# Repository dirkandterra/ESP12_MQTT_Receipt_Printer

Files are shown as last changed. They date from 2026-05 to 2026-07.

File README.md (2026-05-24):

# ESP-12 MQTT Receipt Printer

Controls a generic 58mm ESC/POS thermal printer over UART from an ESP-12 (ESP8266) module. Subscribes to an MQTT topic and prints any message received.

## Hardware

| Signal | ESP-12 pin | Notes |
|---|---|---|
| UART TX | GPIO2 (UART1) | Connect to printer RX |
| GND | GND | Common ground with printer |

UART1 on ESP8266 is TX-only (GPIO2), which is sufficient — ESC/POS printers do not require RX for normal printing.

Printer power: most 58mm printers need 5–9 V at up to 2 A. Do **not** power from the ESP module.

## Configuration

Copy `main/secret.h.example` to `main/secret.h` and fill in your credentials:

```c
#define WIFI_SSID      "your_ssid"
#define WIFI_PWD       "your_password"
#define MQTT_SERVER    "your.broker.ip"
#define MOSQUITTO_USR  "username"
#define MOSQUITTO_PWD  "password"
```

The MQTT topic is defined in `main/main.c`:
```c
const char *mqtt_topic = "ESP12_Receipt/print";
```

Printer settings (UART port, baud rate) are in `idf.py menuconfig` → Receipt Printer.

## Build

Requires [ESP8266_RTOS_SDK](https://github.com/espressif/ESP8266_RTOS_SDK) v3.4 or later.

```bash
export IDF_PATH=/path/to/ESP8266_RTOS_SDK
idf.py build
idf.py -p /dev/ttyUSB0 flash
```

## Behaviour

- On boot, the IP address is printed on the receipt paper.
- Any message published to the MQTT topic is printed in Font B (condensed).
- WiFi: retries 5 times on disconnect, then pauses 5 minutes before trying again.
- MQTT: auto-reconnects indefinitely; re-subscribes on each reconnect.

## Project structure

```
main/
  main.c            WiFi init, MQTT topic, app entry
  printer.c/.h      ESC/POS UART driver
  mqtt_printer.c/.h MQTT subscriber → printer
  secret.h          WiFi & MQTT credentials (not in repo)
```

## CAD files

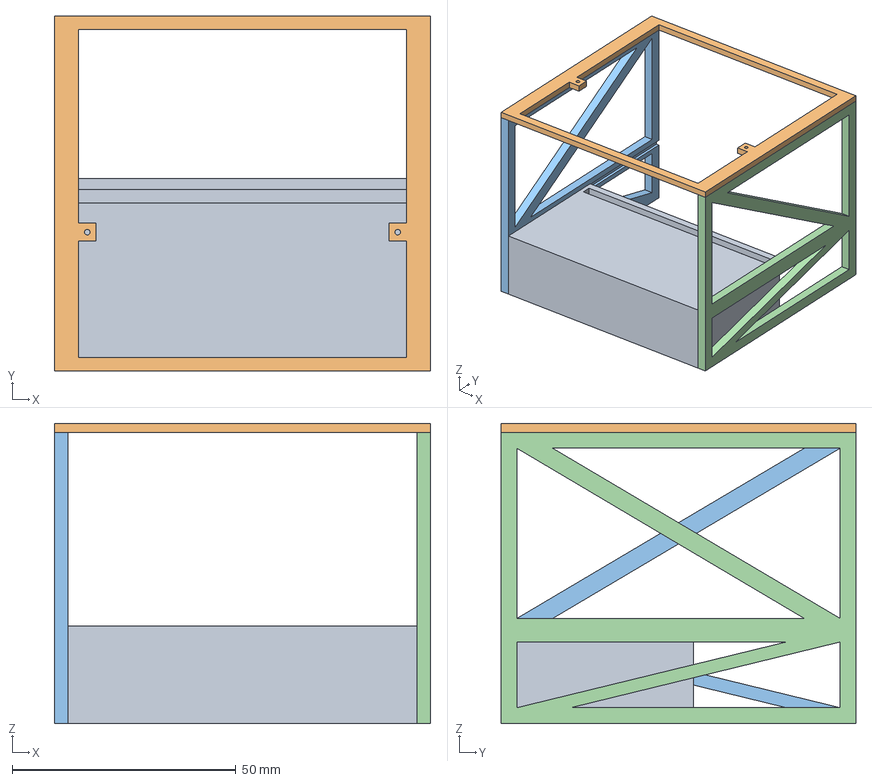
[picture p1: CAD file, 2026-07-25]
CAD/ReceiptPrinterAssembly.FCStd
84.0 x 79.3 x 67.0 mm

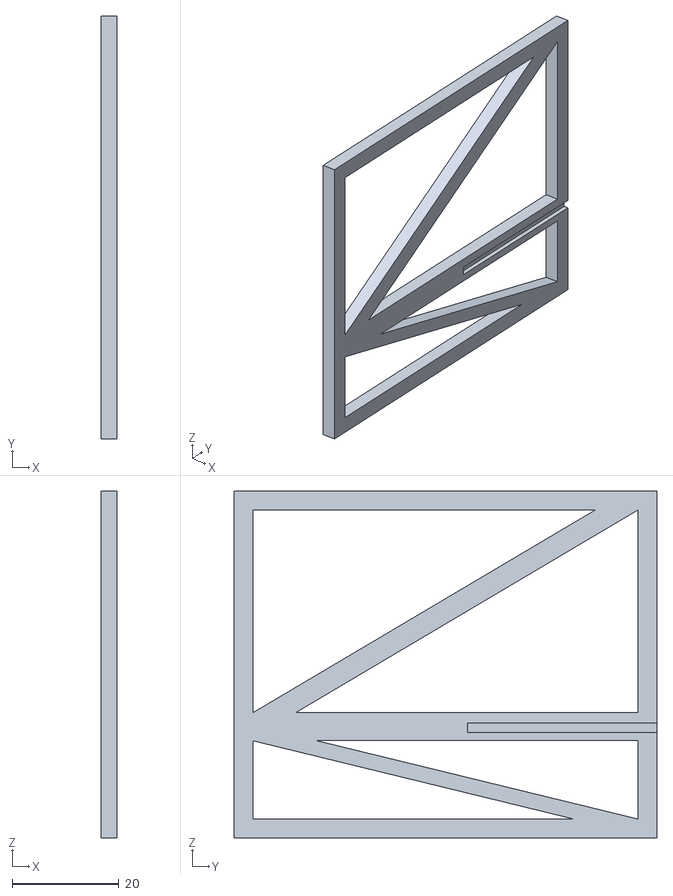
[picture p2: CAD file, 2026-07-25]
CAD/ReceiptPrinterSide1.stl
3.00 x 79.2 x 65.0

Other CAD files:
CAD/ReceiptPrinterSide2.stl

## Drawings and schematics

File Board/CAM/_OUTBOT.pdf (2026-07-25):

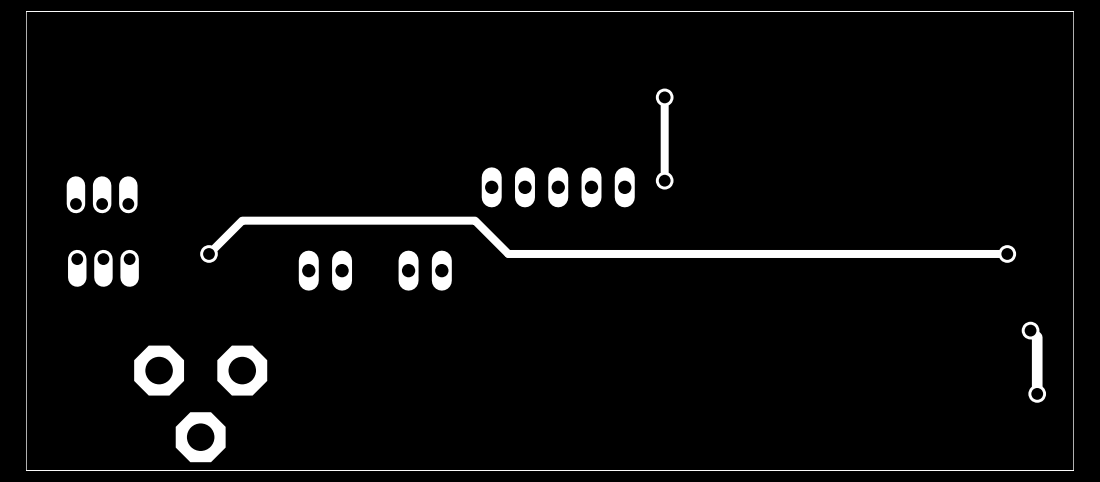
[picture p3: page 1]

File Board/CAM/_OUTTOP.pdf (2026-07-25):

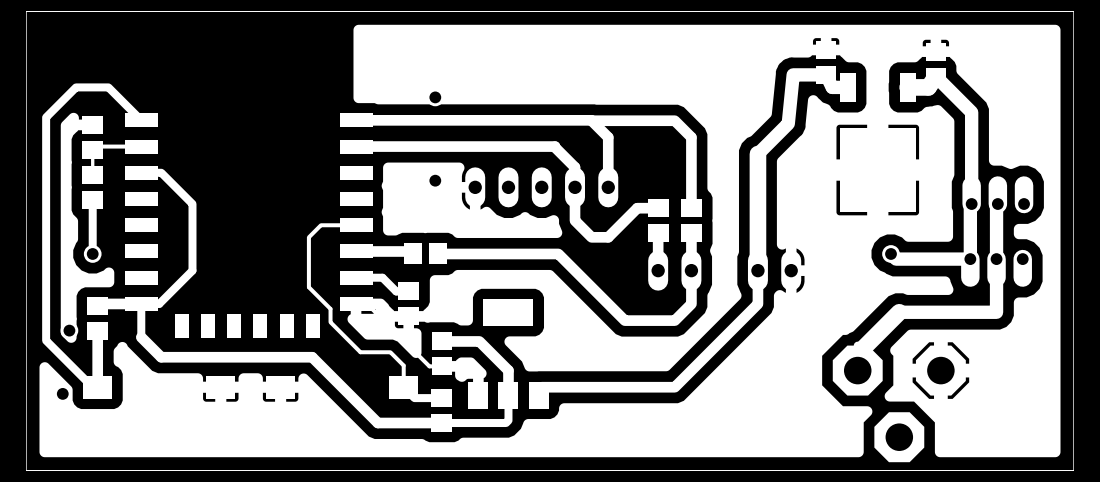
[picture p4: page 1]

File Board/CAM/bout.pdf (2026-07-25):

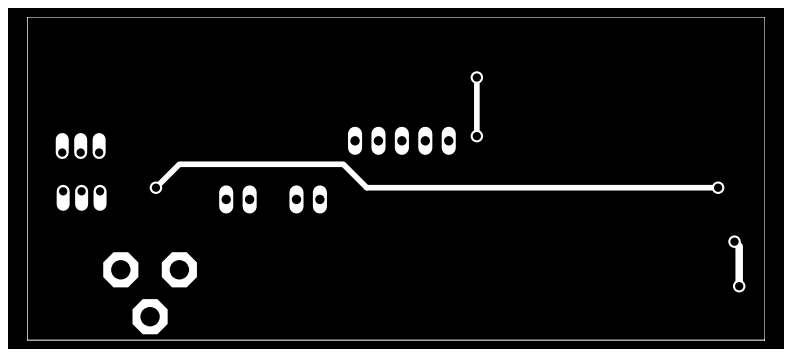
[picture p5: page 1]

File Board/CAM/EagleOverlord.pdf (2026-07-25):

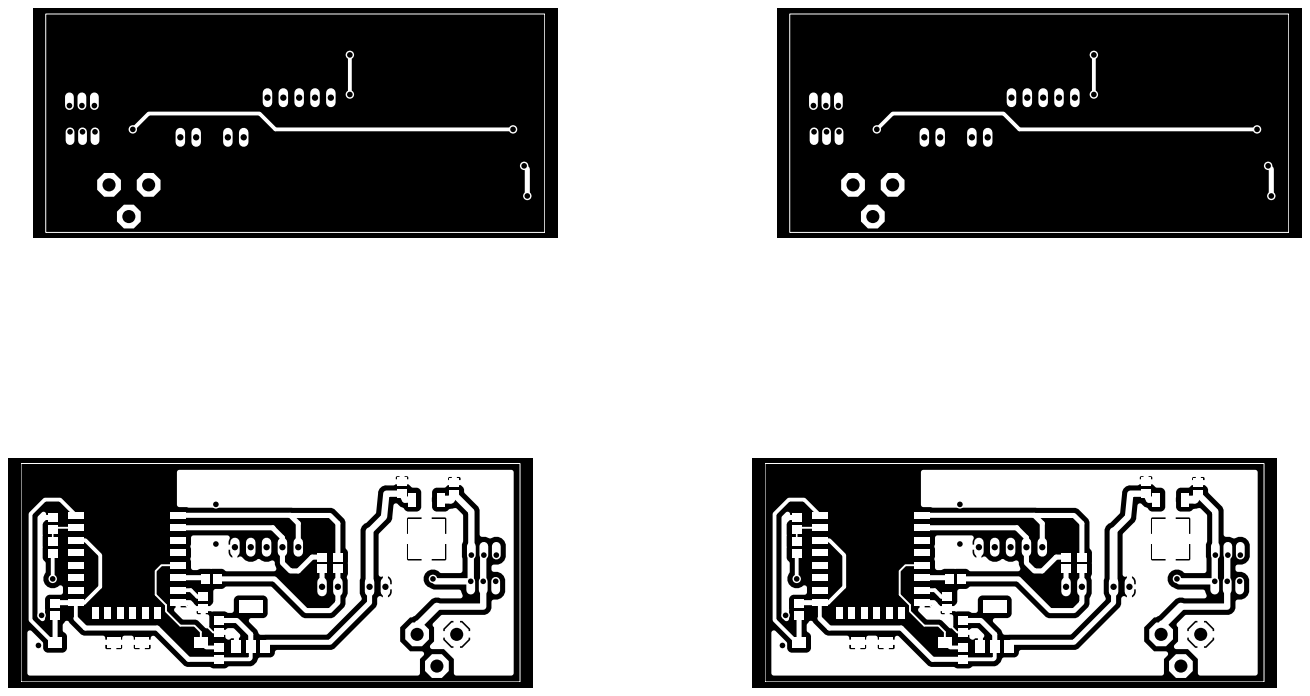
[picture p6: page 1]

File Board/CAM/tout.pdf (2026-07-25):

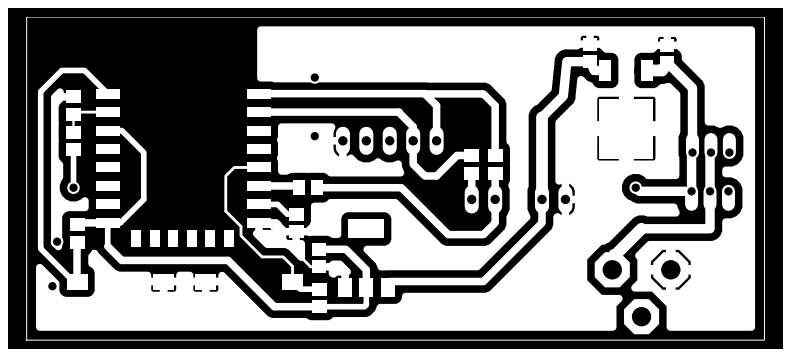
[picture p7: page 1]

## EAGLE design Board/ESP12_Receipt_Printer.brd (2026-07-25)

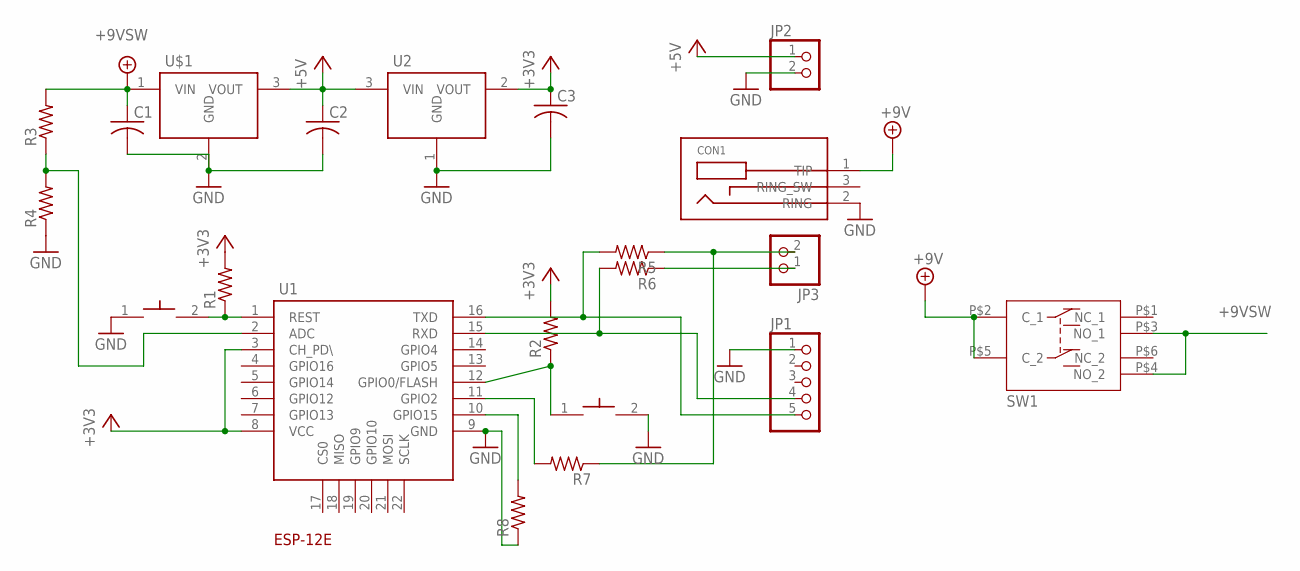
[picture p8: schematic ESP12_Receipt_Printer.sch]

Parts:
BTN1, BTN2: FSMSM_SWITCH_6X3.6; SMD-2-SWITCH
C1, C2, C3: C-USC0805; C0805
CON1: BARREL_JACK_3PINPJ-102A_2MM_HOLES; PJ-102A_2MM_HOLES
JP1: PINHD-1X5/90; 1X05/90
JP2, JP3: PINHD-1X2/90; 1X02/90
R1, R2, R3, R4, R5, R6, R7, R8: R-US_M0805; M0805
SW1: SW_TOGGLE_6PIN_DPDT; BTN_6PIN
U1: ESP-12E
U2: AMS1117; SOT223
U$1: 7805; TO252-3

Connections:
+3V3: C3.1, R1.2, R2.2, U1.3 (CH_PD\), U1.8 (VCC), U2.2 (VOUT)
+5V: C2.1, JP2.1, U2.3 (VIN), U$1.3 (VOUT)
+9VSW: C1.1, R3.2, SW1.P$3 (NO_1), SW1.P$4 (NO_2), U$1.1 (VIN)
+9V_SW: CON1.1 (TIP), SW1.P$2 (C_1), SW1.P$5 (C_2)
GND: BTN1.2, BTN2.1, C1.2, C2.2, C3.2, CON1.2 (RING), JP1.1, JP2.2, R4.1, R8.1, U1.9 (GND), U2.1 (GND), U$1.2 (GND)
unnamed: BTN1.1, R2.1, U1.12 (GPIO0/FLASH)
unnamed: BTN2.2, R1.1, U1.1 (REST)
unnamed: JP1.4, R6.2, U1.15 (RXD)
unnamed: JP1.5, R5.2, U1.16 (TXD)
unnamed: R3.1, R4.2, U1.2 (ADC)
unnamed: JP3.1, R6.1
unnamed: R8.2, U1.10 (GPIO15)
unnamed: R7.2, U1.11 (GPIO2)
unnamed: JP3.2, R5.1, R7.1

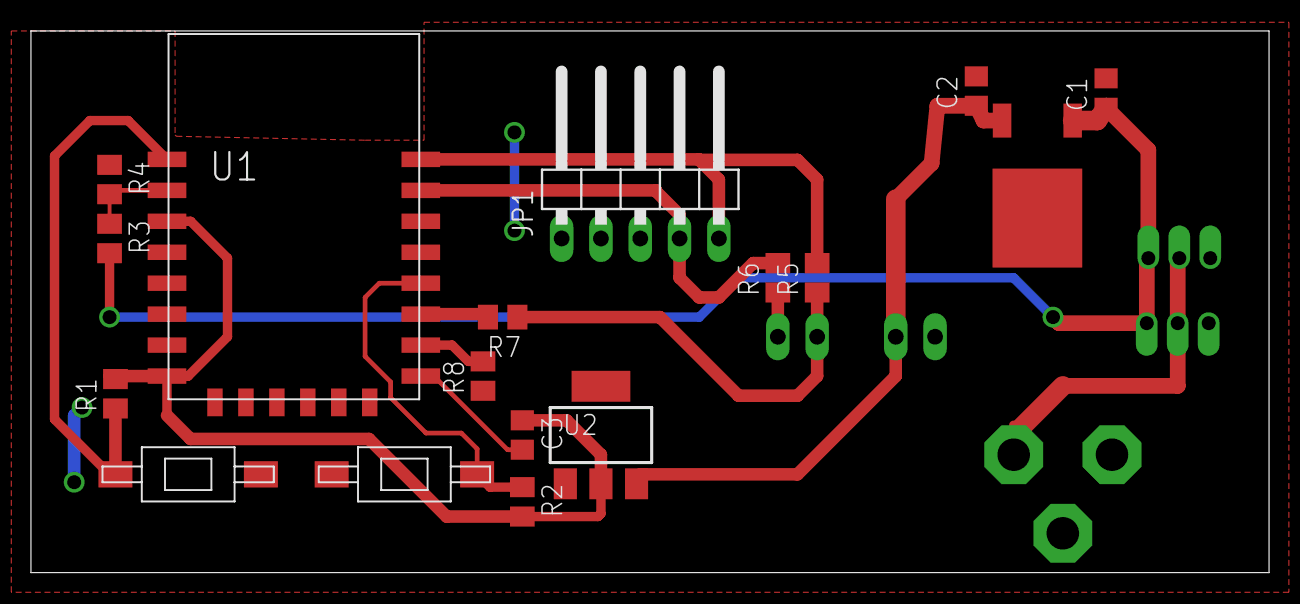
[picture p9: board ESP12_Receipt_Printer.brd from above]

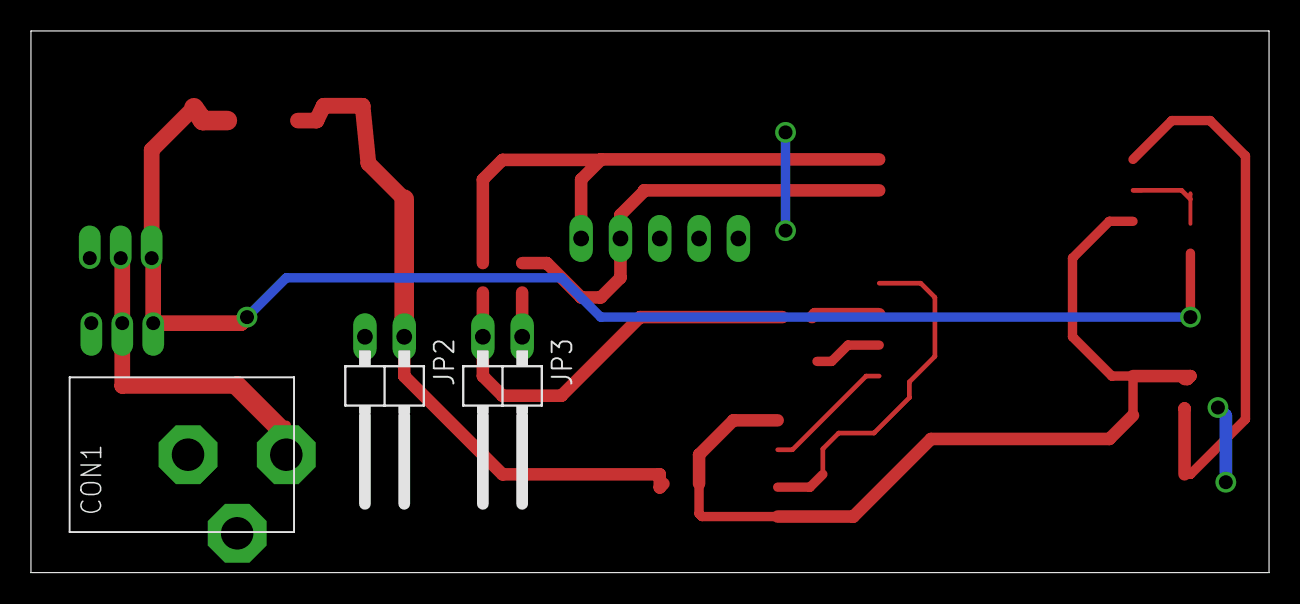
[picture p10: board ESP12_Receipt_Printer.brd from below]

Board: 2 copper layers, 80.0 x 35.0 mm, 21 parts (3 on the bottom side), 14 nets.

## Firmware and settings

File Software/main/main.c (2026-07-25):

#include <string.h>
#include "freertos/FreeRTOS.h"
#include "freertos/task.h"
#include "freertos/event_groups.h"
#include "freertos/timers.h"
#include "esp_system.h"
#include "esp_wifi.h"
#include "esp_event_loop.h"
#include "esp_log.h"
#include "nvs_flash.h"
#include "tcpip_adapter.h"
#include "driver/adc.h"

#include "secret.h"
#include "printer.h"
#include "mqtt_printer.h"

static const char *TAG = "receipt";

const char *mqtt_topic = "ESP12_Receipt/print";

static EventGroupHandle_t wifi_event_group;

static int retry_count;
static float batteryVoltage;
static TimerHandle_t s_retry_timer;
#define WIFI_CONNECTED_BIT  BIT0
#define WIFI_MAX_RETRY      5
#define WIFI_PAUSE_MS       (5 * 60 * 1000)
#define VOLTAGE_DIVIDER_RATIO (7.48/(74.7+7.48))  // R1=75k, R2=7.5k

/* ---------------------------------------------------------- wifi callbacks */

static void wifi_retry_timer_cb(TimerHandle_t t)
{
    retry_count = 0;
    ESP_LOGI(TAG, "WiFi retry pause over, restarting reconnect cycle");
    esp_wifi_connect();
}

static esp_err_t on_wifi_event(void *ctx, system_event_t *ev)
{
    switch (ev->event_id) {

    case SYSTEM_EVENT_STA_START:
        esp_wifi_connect();
        break;

    case SYSTEM_EVENT_STA_GOT_IP: {
        char ip_str[32];
        snprintf(ip_str, sizeof(ip_str), "IP: " IPSTR "\n",
                 IP2STR(&ev->event_info.got_ip.ip_info.ip));
        ESP_LOGI(TAG, "%s", ip_str);
        printer_println(ip_str);
        retry_count = 0;
        xTimerStop(s_retry_timer, 0);
        xEventGroupSetBits(wifi_event_group, WIFI_CONNECTED_BIT);
        break;
    }

    case SYSTEM_EVENT_STA_DISCONNECTED:
        if (retry_count < WIFI_MAX_RETRY) {
            retry_count++;
            ESP_LOGW(TAG, "WiFi disconnected, reconnecting (%d/%d)...",
                     retry_count, WIFI_MAX_RETRY);
            esp_wifi_connect();
        } else {
            ESP_LOGE(TAG, "WiFi failed after %d attempts, pausing 5 min", WIFI_MAX_RETRY);
            xTimerStart(s_retry_timer, 0);
        }
        break;

    default:
        break;
    }
    return ESP_OK;
}

/* ---------------------------------------------------------- wifi init */

static void wifi_init_sta(void)
{
    wifi_event_group = xEventGroupCreate();
    s_retry_timer = xTimerCreate("wifi_retry", pdMS_TO_TICKS(WIFI_PAUSE_MS),
                                 pdFALSE, NULL, wifi_retry_timer_cb);

    tcpip_adapter_init();
    ESP_ERROR_CHECK(esp_event_loop_init(on_wifi_event, NULL));

    wifi_init_config_t cfg = WIFI_INIT_CONFIG_DEFAULT();
    ESP_ERROR_CHECK(esp_wifi_init(&cfg));
    ESP_ERROR_CHECK(esp_wifi_set_storage(WIFI_STORAGE_RAM));

    wifi_config_t wifi_cfg = {
        .sta = {
            .ssid     = WIFI_SSID,
            .password = WIFI_PWD,
        },
    };
    ESP_ERROR_CHECK(esp_wifi_set_mode(WIFI_MODE_STA));
    ESP_ERROR_CHECK(esp_wifi_set_config(ESP_IF_WIFI_STA, &wifi_cfg));
    ESP_ERROR_CHECK(esp_wifi_start());

    xEventGroupWaitBits(wifi_event_group, WIFI_CONNECTED_BIT,
                        pdFALSE, pdFALSE, portMAX_DELAY);
    ESP_LOGI(TAG, "WiFi connected to \"%s\"", WIFI_SSID);
}

/*----------------------------------------------------------- read battery level */
static void battery_timer_cb(TimerHandle_t t)
{
    uint16_t raw;
    if(adc_read(&raw) != ESP_OK) {
        ESP_LOGE(TAG, "ADC read failed");
        return;
    }
    batteryVoltage = (float)raw / 1023.0f / VOLTAGE_DIVIDER_RATIO;
    int v_whole = (int)batteryVoltage;
    int v_frac  = (int)((batteryVoltage - v_whole) * 100);
    ESP_LOGI(TAG, "Battery voltage: %d.%02dV (raw=%u)", v_whole, v_frac, raw);

    char buf[16];
    snprintf(buf, sizeof(buf), "%d.%02dV", v_whole, v_frac);
    mqtt_publish("ESP12_Receipt/BattVoltage", buf);
}

/* ---------------------------------------------------------- entry point */

void app_main(void)
{
    ESP_ERROR_CHECK(nvs_flash_init());
    printer_init();
    wifi_init_sta();

    adc_config_t adc_cfg = {
        .mode = ADC_READ_TOUT_MODE,
        .clk_div = 8,
    };
    if(adc_init(&adc_cfg) != ESP_OK) {
        ESP_LOGE(TAG, "ADC init failed");
        return;
    }
    TimerHandle_t battery_timer = xTimerCreate("battery", pdMS_TO_TICKS(60 * 1000), pdTRUE, NULL, battery_timer_cb);
    xTimerStart(battery_timer, 0);

    mqtt_printer_start();
    ESP_LOGI(TAG, "Receipt printer ready, listening on %s", mqtt_topic);
}

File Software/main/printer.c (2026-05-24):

#include "printer.h"
#include "freertos/FreeRTOS.h"
#include "driver/uart.h"
#include "esp_log.h"
#include <string.h>

static const char *TAG = "printer";

#define UART_NUM    CONFIG_PRINTER_UART_NUM
#define BAUD        CONFIG_PRINTER_BAUD_RATE

static void send(const uint8_t *buf, size_t len)
{
    uart_write_bytes(UART_NUM, (const char *)buf, len);
}

void printer_init(void)
{
    uart_config_t cfg = {
        .baud_rate  = BAUD,
        .data_bits  = UART_DATA_8_BITS,
        .parity     = UART_PARITY_DISABLE,
        .stop_bits  = UART_STOP_BITS_1,
        .flow_ctrl  = UART_HW_FLOWCTRL_DISABLE,
    };
    ESP_ERROR_CHECK(uart_param_config(UART_NUM, &cfg));
    /* ESP8266 UART pins are hardware-fixed: UART1 TX is GPIO2, no software remap needed */
    ESP_ERROR_CHECK(uart_driver_install(UART_NUM, 0, 256, 0, NULL, 0));

    printer_reset();
    ESP_LOGI(TAG, "ready on UART%d (GPIO2 TX) %d baud", UART_NUM, BAUD);
}

void printer_reset(void)
{
    const uint8_t cmd[] = {0x1B, 0x40}; /* ESC @ */
    send(cmd, sizeof(cmd));
}

void printer_write(const char *data, size_t len)
{
    uart_write_bytes(UART_NUM, data, len);
}

void printer_println(const char *text)
{
    uart_write_bytes(UART_NUM, text, strlen(text));
    uart_write_bytes(UART_NUM, "\n", 1);
}

void printer_set_align(printer_align_t align)
{
    const uint8_t cmd[] = {0x1B, 0x61, (uint8_t)align}; /* ESC a n */
    send(cmd, sizeof(cmd));
}

void printer_set_bold(bool bold)
{
    const uint8_t cmd[] = {0x1B, 0x45, bold ? 0x01 : 0x00}; /* ESC E n */
    send(cmd, sizeof(cmd));
}

void printer_set_size(printer_size_t size)
{
    if (size == PRINTER_SIZE_SMALL) {
        const uint8_t cmd[] = {0x1B, 0x4D, 0x01}; /* ESC M 1 — Font B */
        send(cmd, sizeof(cmd));
    } else {
        const uint8_t font_a[] = {0x1B, 0x4D, 0x00}; /* ESC M 0 — Font A */
        send(font_a, sizeof(font_a));
        const uint8_t cmd[] = {0x1D, 0x21, (uint8_t)size}; /* GS ! n */
        send(cmd, sizeof(cmd));
    }
}

void printer_set_underline(uint8_t weight)
{
    const uint8_t cmd[] = {0x1B, 0x2D, weight}; /* ESC - n */
    send(cmd, sizeof(cmd));
}

void printer_feed(uint8_t lines)
{
    const uint8_t cmd[] = {0x1B, 0x64, lines}; /* ESC d n */
    send(cmd, sizeof(cmd));
}

void printer_cut(void)
{
    printer_feed(4);
    const uint8_t cmd[] = {0x1D, 0x56, 0x41, 0x03}; /* GS V A 3 — partial cut */
    send(cmd, sizeof(cmd));
}

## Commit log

2026-05-24 Initial commit: ESP8266 MQTT receipt printer
    Replaces HTTP server with MQTT subscriber. Connects to WiFi,
    subscribes to ESP12_Receipt/print topic, and prints incoming
    messages via ESC/POS on UART1 (GPIO2). WiFi retries 5 times
    then pauses 5 min before cycling again.
    [main.c, printer.c]
2026-05-30 Added board files
    [ESP12_Receipt_Printer.brd, ESP12_Receipt_Printer.sch, ReceiptPrinterAssembly.FCStd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]
2026-07-25 Add battery voltage reporting via ADC over MQTT
    Reads TOUT via adc_read() on a 1-minute timer and publishes the
    computed voltage to ESP12_Receipt/BattVoltage. Fixes an unparenthesized
    VOLTAGE_DIVIDER_RATIO macro that silently collapsed every reading to
    0.00V regardless of the actual ADC value.
    [main.c]
2026-07-25 Updated to correct board files
    [ESP12_Receipt_Printer.brd, ESP12_Receipt_Printer.sch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]
